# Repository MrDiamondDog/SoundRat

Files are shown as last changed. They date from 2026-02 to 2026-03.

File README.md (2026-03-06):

# SoundRat

A desktop sound mixer for controlling the volumes of applications on your computer. This repo contains CAD, PCB, firmware, and software.

Includes 5 rotary encoders (with buttons!), 16 RGB LEDs, and an RP2040-zero microcontroller, all on a custom PCB in a custom case!

The software runs on your computer and reads from SoundRat to update application volumes, the firmware simply sends that data over and receives volume/peak data.

I made this project as a replacement for my very crude Deej that performs a similar function. It is simply an Arduino Uno and 5 linear potentiometers and does its job, but leaves much to be desired. I wanted more out of it, especially being a sound guy at my school's theatre, I wanted to see the volume levels accurately (cause the linear pots are really terrible), and peak level LED indicators (basically visualizing the current volume of the audio outputting from the application). Deej is a really cool project, as it is just an Arduino project you load onto a nano and software that runs really nicely. It's easily customizable and I hope to do that here as well. I've already found a lot of use out of my Deej, and I figured it would make a good project to make a spirtual successor.

A lot of inspiration is taken from Deej (check it out [here](https://github.com/omriharel/deej)), but all designs are by me!

## Images

Case



Routing



PCB



Schematic



Full Assembly




## BOM

All items from Aliexpress

| Name | Qtd | Price | Shipping | Link |
| ---- | --- | ----- | --- | ---- |
| RP2040-Zero RP2040 for Raspberry Pi Microcontroller PICO Development Board Module Dual-core Cortex M0+ Processor 2MB Flash | 1 | $1.99 | $0 | https://www.aliexpress.us/item/3256807207087581.html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 |
| 5PCS 360 Degree Rotary Encoder EC12 RE12 Audio Encoder Coding 5Pin 24 Position With Push Button Switch Handle Length 12.5MM | 1x5pcs | $2.56 | $0 | https://www.aliexpress.us/item/3256801922952476.html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 |
| 2~1000Pcs 4 Color in 1 SK6812 RGBW RGBWW RGBNW WWA RGB White SMD 3535 5050 Individually Addressable LED Chip Pixel as WS2812B 5V | 2x10pcs | $5.03 | $3.98 | https://www.aliexpress.us/item/2251832480376635.html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 |
| PCB from JLCPCB | 1x5pcs | $2.00 | $3.12 |

**Total**: $23.77

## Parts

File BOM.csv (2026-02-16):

Name | Description | Quantity | Price | URL
RP2040-Zero RP2040 for Raspberry Pi Microcontroller PICO Development Board Module Dual-core Cortex M0+ Processor 2MB Flash | RP2040-Zero Microcontroller | 1 | $1.99 | https://www.aliexpress.us/item/3256807207087581.html?mp=1
5PCS 360 Degree Rotary Encoder EC12 RE12 Audio Encoder Coding 5Pin 24 Position With Push Button Switch Handle Length 12.5MM | 5 EC12 Rotary Encoders with Buttons | 1x5pcs | $2.56 | https://www.aliexpress.us/item/3256801922952476.html?mp=1
2~1000Pcs 4 Color in 1 SK6812 RGBW RGBWW RGBNW WWA RGB White SMD 3535 5050 Individually Addressable LED Chip Pixel as WS2812B 5V | 10pcs SK6812 RGBW LEDs | 2x10pcs | $9.01 | https://www.aliexpress.us/item/2251832480376635.html?mp=1
PCB from JLCPCB | PCB from JLCPCB | 1x5pcs | $5.12

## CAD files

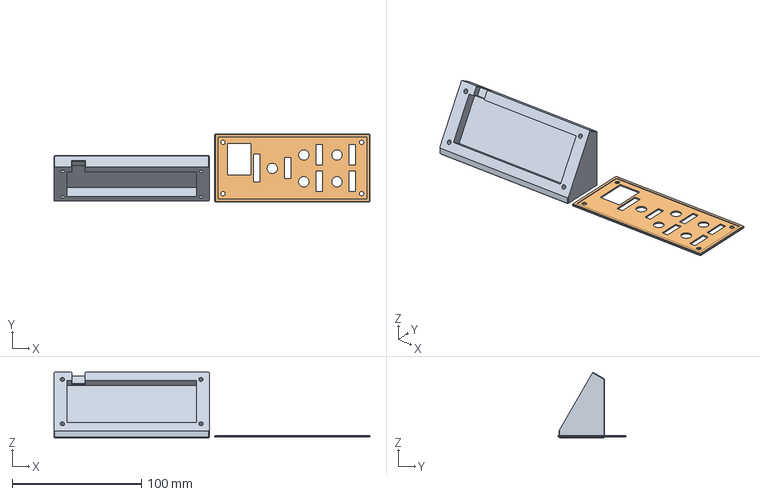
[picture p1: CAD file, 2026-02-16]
cad/SoundRat.step
244.2 x 52.6 x 50.8 mm

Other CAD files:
cad/SoundRat.f3d

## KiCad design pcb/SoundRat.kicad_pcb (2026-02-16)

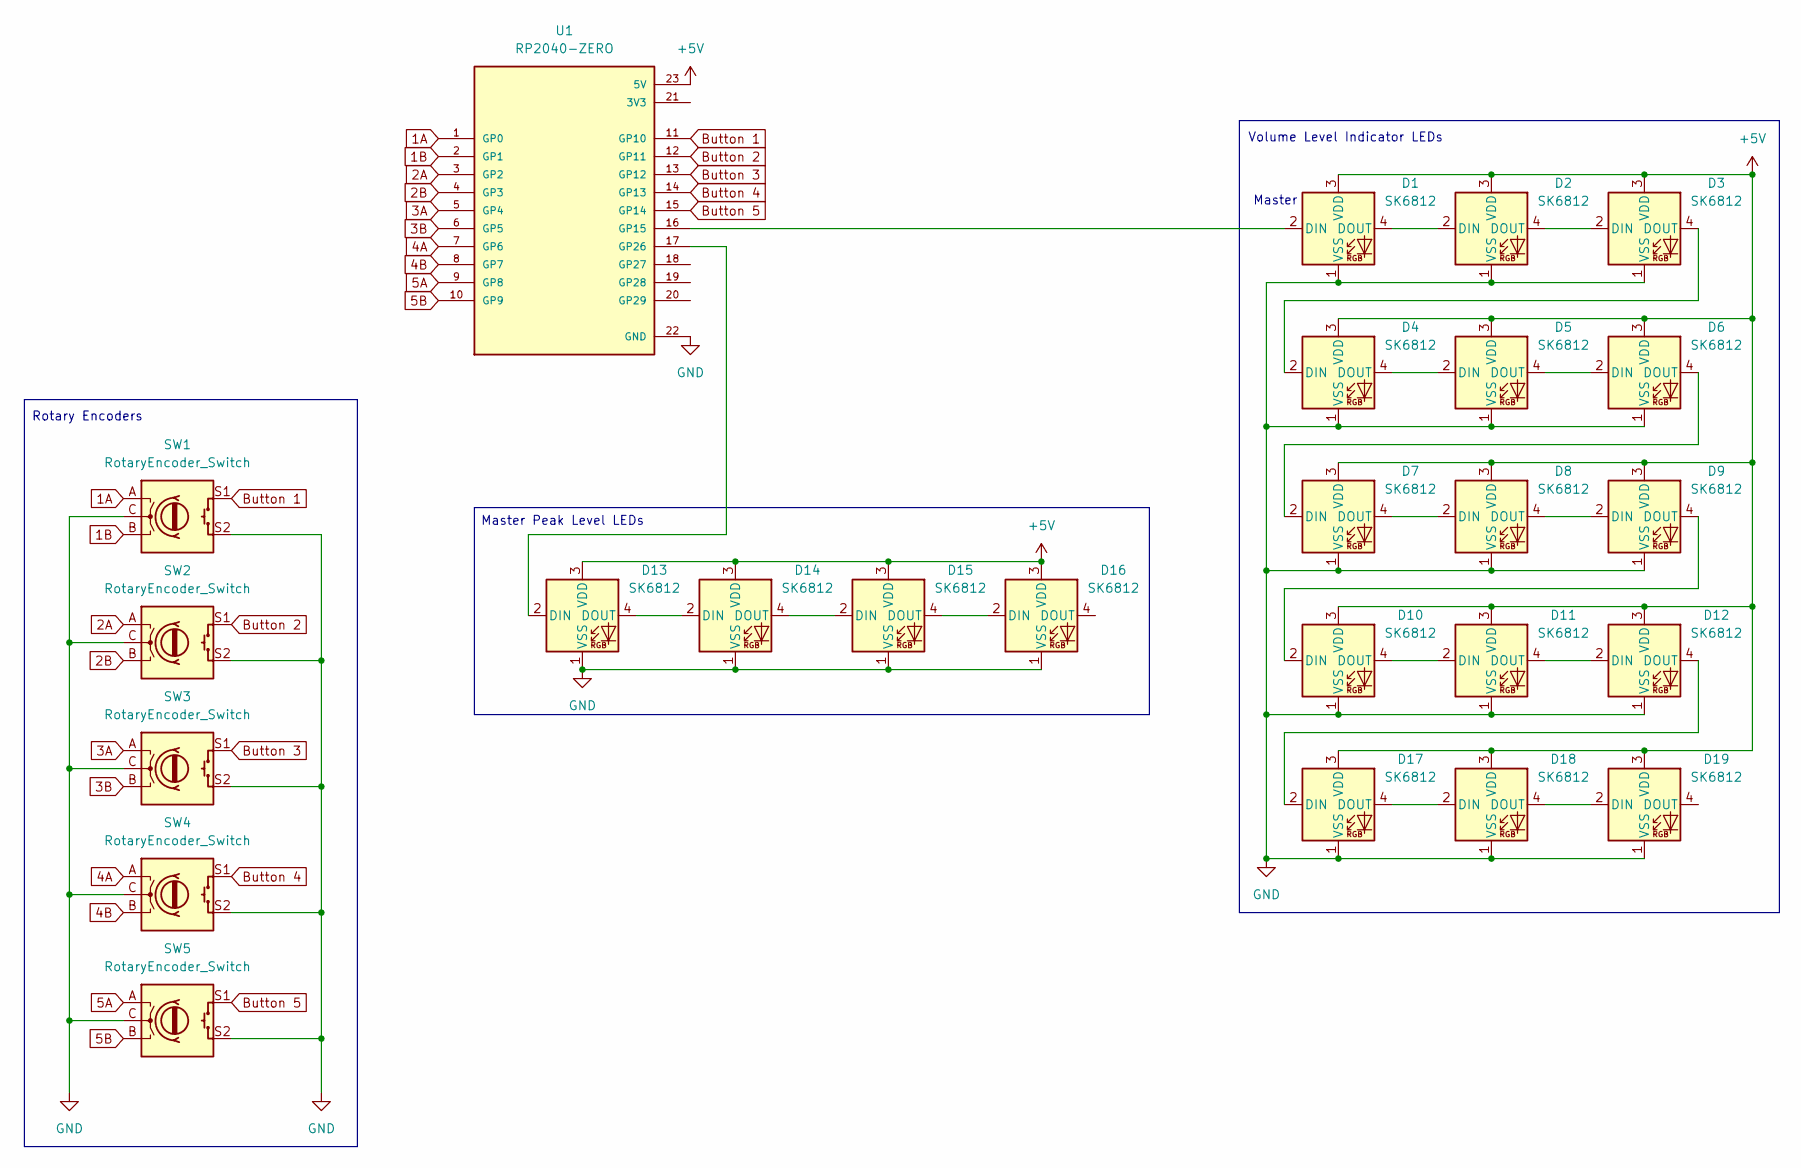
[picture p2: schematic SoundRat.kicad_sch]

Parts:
D1, D2, D3, D4, D5, D6, D7, D8, D9, D10, D11, D12, D13, D14, D15, D16, D17, D18, D19: SK6812; LED_SK6812_PLCC4_5.0x5.0mm_P3.2mm
SW1, SW2, SW3, SW4, SW5: RotaryEncoder_Switch; RotaryEncoder_Bourns_Vertical_PEC12R-3x17F-Sxxxx
U1: RP2040-ZERO; MODULE_RP2040-ZERO; PARTREV NA

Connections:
1A: SW1.A, U1.1 (GP0)
1B: SW1.B, U1.2 (GP1)
2A: SW2.A, U1.3 (GP2)
2B: SW2.B, U1.4 (GP3)
3A: SW3.A, U1.5 (GP4)
3B: SW3.B, U1.6 (GP5)
4A: SW4.A, U1.7 (GP6)
4B: SW4.B, U1.8 (GP7)
5A: SW5.A, U1.9 (GP8)
5B: SW5.B, U1.10 (GP9)
+5V: D1.3 (VDD), D2.3 (VDD), D3.3 (VDD), D4.3 (VDD), D5.3 (VDD), D6.3 (VDD), D7.3 (VDD), D8.3 (VDD), D9.3 (VDD), D10.3 (VDD), D11.3 (VDD), D12.3 (VDD), D13.3 (VDD), D14.3 (VDD), D15.3 (VDD), D16.3 (VDD), D17.3 (VDD), D18.3 (VDD), D19.3 (VDD), U1.23 (5V)
Button 1: SW1.S1, U1.11 (GP10)
Button 2: SW2.S1, U1.12 (GP11)
Button 3: SW3.S1, U1.13 (GP12)
Button 4: SW4.S1, U1.14 (GP13)
Button 5: SW5.S1, U1.15 (GP14)
GND: D1.1 (VSS), D2.1 (VSS), D3.1 (VSS), D4.1 (VSS), D5.1 (VSS), D6.1 (VSS), D7.1 (VSS), D8.1 (VSS), D9.1 (VSS), D10.1 (VSS), D11.1 (VSS), D12.1 (VSS), D13.1 (VSS), D14.1 (VSS), D15.1 (VSS), D16.1 (VSS), D17.1 (VSS), D18.1 (VSS), D19.1 (VSS), SW1.C, SW1.S2, SW2.C, SW2.S2, SW3.C, SW3.S2, SW4.C, SW4.S2, SW5.C, SW5.S2, U1.22 (GND)
unnamed: D1.2 (DIN), U1.16 (GP15)
unnamed: D1.4 (DOUT), D2.2 (DIN)
unnamed: D2.4 (DOUT), D3.2 (DIN)
unnamed: D3.4 (DOUT), D4.2 (DIN)
unnamed: D4.4 (DOUT), D5.2 (DIN)
unnamed: D5.4 (DOUT), D6.2 (DIN)
unnamed: D6.4 (DOUT), D7.2 (DIN)
unnamed: D7.4 (DOUT), D8.2 (DIN)
unnamed: D8.4 (DOUT), D9.2 (DIN)
unnamed: D9.4 (DOUT), D10.2 (DIN)
unnamed: D10.4 (DOUT), D11.2 (DIN)
unnamed: D11.4 (DOUT), D12.2 (DIN)
unnamed: D12.4 (DOUT), D17.2 (DIN)
unnamed: D13.2 (DIN), U1.17 (GP26)
unnamed: D13.4 (DOUT), D14.2 (DIN)
unnamed: D14.4 (DOUT), D15.2 (DIN)
unnamed: D15.4 (DOUT), D16.2 (DIN)
unnamed: D17.4 (DOUT), D18.2 (DIN)
unnamed: D18.4 (DOUT), D19.2 (DIN)

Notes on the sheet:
Master Peak Level LEDs
Rotary Encoders
Volume Level Indicator LEDs
Master

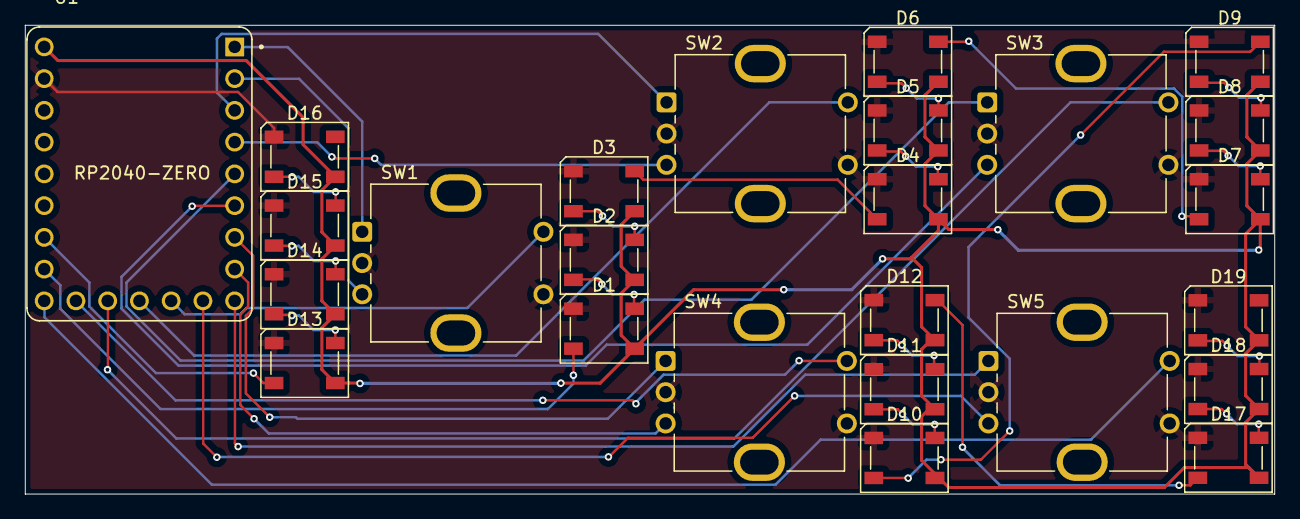
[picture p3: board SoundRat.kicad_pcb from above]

Board: 2 copper layers, 99.9 x 37.5 mm, 25 parts (0 on the bottom side), 36 nets.

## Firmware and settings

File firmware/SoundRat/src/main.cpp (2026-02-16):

#include <Arduino.h>

#define EC_1A 0
#define EC_1B 1
#define EC_BTN_1 10

#define EC_2A 2
#define EC_2B 3
#define EC_BTN_2 11

#define EC_3A 4
#define EC_3B 5
#define EC_BTN_3 12

#define EC_4A 6
#define EC_4B 7
#define EC_BTN_4 13

#define EC_5A 8
#define EC_5B 9
#define EC_BTN_5 14

#define LED_VOL 15
#define LED_PEAK 26

typedef struct {
  uint8_t a, b, btn, pos, lastPos;
} encoder_t;

encoder_t encoders[] = {
  { EC_1A, EC_1B, EC_BTN_1, 50, 50 },
  { EC_2A, EC_2B, EC_BTN_2, 50, 50 },
  { EC_3A, EC_3B, EC_BTN_3, 50, 50 },
  { EC_4A, EC_4B, EC_BTN_4, 50, 50 },
  { EC_5A, EC_5B, EC_BTN_5, 50, 50 }
};

void setup() {
  Serial.begin(115200);
  
  for (int i = 0; i < sizeof(encoders); i++) {
    pinMode(encoders[i].a, INPUT_PULLUP);
    pinMode(encoders[i].b, INPUT_PULLUP);
    pinMode(encoders[i].btn, INPUT_PULLUP);

    attachInterrupt(encoders[i].a, [i]() { on_encoder_change(i) }, CHANGE);
  }

  pinMode(LED_VOL, OUTPUT);
  pinMode(LED_PEAK, OUTPUT);
}

// encoders are a lot more complicated than i thought
// https://www.build-electronic-circuits.com/arduino-rotary-encoder/
void on_encoder_change(int i) {
  int MSB = digitalRead(encoderPinA); // MSB = most significant bit
  int LSB = digitalRead(encoderPinB); // LSB = least significant bit

  // bitshifting my behated
  int encoded = (MSB << 1) | LSB;
  int sum = (encoders[i].lastPos << 2) | encoded;

  if(sum == 0b1101 || sum == 0b0100 || sum == 0b0010 || sum == 0b1011) encoders[i].pos++;
  if(sum == 0b1110 || sum == 0b0111 || sum == 0b0001 || sum == 0b1000) encoders[i].pos--;

  encoders[i].lastPos = encoders[i].pos;
}

std::string get_encoder_data(int i) {
  return encoders[i].pos + "," + digitalRead(encoders[i].btn);
}

std::string print_data() {
  std::string data = "";

  for (int i = 0; i < sizeof(encoders); i++) {
    data = data + get_encoder_data(i) + ";";
  }

  return data;
}

void read_serial_data() {
  char endMarker = '\n';
  std::string received = "";
  
  while (Serial.available() > 0) {
    char c = Serial.read();
    
    received += c;

    if (c == "\n")
      break;
  }

  return received;
}

void loop() {
  delay(50);

  // simply print the data for all the encoders for the computer to read
  print_data();

  // then read whatever is coming in to display peak levels
  read_serial_data();

  // TODO: update LEDs
}
